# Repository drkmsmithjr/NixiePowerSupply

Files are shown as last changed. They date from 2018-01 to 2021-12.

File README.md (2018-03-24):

# [Nixie Tube Power Supply](https://wp.me/p85ddV-B1 )

See [www.surfncircuits.com](https://wp.me/p85ddV-B1)  for a complete description.  This github repository contains the Kicad Schematic, Spice Simulation, Efficiency Calculations of the 5v to 170v DCM Boost Converter for Powering your Nixie Tubes.   

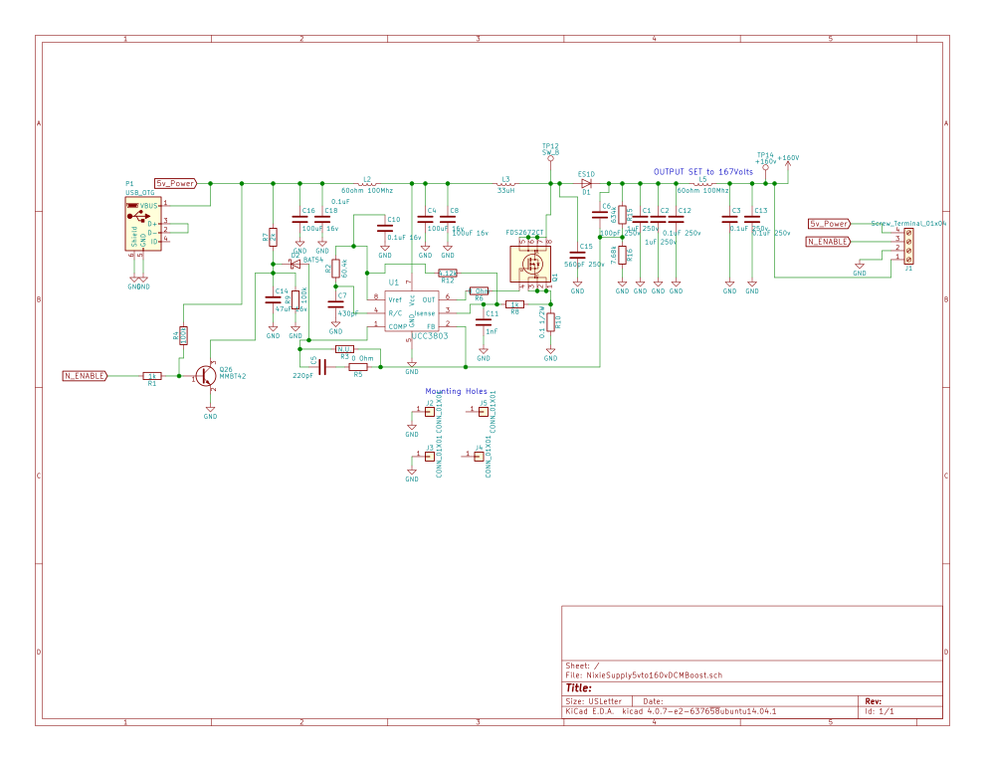
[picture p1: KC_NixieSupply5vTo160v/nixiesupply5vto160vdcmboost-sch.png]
PNG of the Schematic

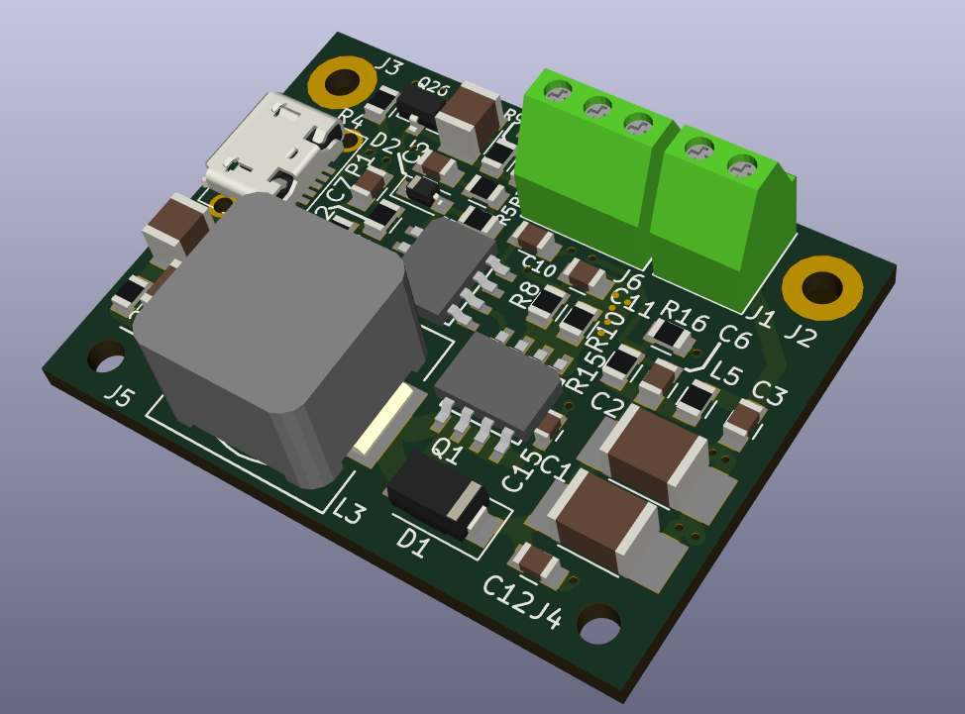
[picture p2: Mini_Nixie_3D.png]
3D image of Rev 3 Mini Board


__KC_NixieSupply5vto160v__:  Kicad schematic, PCB layout, BOM.  The footprint is 1.5" x 1.5" and was described and optimized in Part 2 of the blog.     The Board can be ordered from __oshpark.com__.

__KC_NixieSupply5vto170vMini__:  KiCad schematic, PCB Layout, BOM of the "mini" version of the supply.   This has a footprint of 1.5" x 1" by using smaller output capacitors and using the KiCad power tools to shrink the layout.  This is the system defined by part 3 of the blog.    The layout has all the same constraints as in Part 2.  It still has four mounting holes, a USB input connector and a Terminal output connector.    You can order the board from __oshpark.com__. 

__SimCalcFiles__:  Spice simulation files and DCM Efficiency Calculations.  NOTE: The LTSPICE (TM) simulation has trouble finding an initial operating point.   To get the simulation to start, use the ESC key and press it twice to skip the initial operating point.   This allows the simulation to continue and will provide a good transient response.    

__Datasheeets__: Datasheets for different inductors and the power fet.  In the Kicad Schematic, the part numbers and Digikey (TM) links are listed already.   Also the complete BOM is located in the KICAD Directory.      

See the complete blogs entry at  www.surfncircuits.com
  * [Designing a Small Footprint, Low Profile 5v to 170v Nixie Tube Power Supply (Part 1)](https://wp.me/p85ddV-A8 )
  * [Optimizing the design of the 5v to 170v Nixie Tube Power Supply (Part 2)](https://wp.me/p85ddV-B1 )
  * [KiCad Power Tools Help Shrink The Nixie Tube Power Supply (part 3)](https://wp.me/p85ddV-Ck)

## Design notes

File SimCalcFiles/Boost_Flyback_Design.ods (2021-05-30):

 | Boost Converter Calculator
 |  |  |  |  |  | Estimated: Same Core | NixieTubeMicroSupply | PCA core
 |  |  | DCM Boost Losses | DCM design ETD34 | DCM Boost Same as H | Flyback Calculations | Flyback Calculations | Flyback Calculations
 | Vout | Vout | 167 | 167 | 167 | 167 | 167 | 167
 | Vin | Vin | 5 | 5 | 5 | 5 | 5 | 5
 | Flyback Turns Ratio | Secondary/Primary |  |  |  | 5 | 8 | 10.4
 | Duty for CCM of operation | D_CCM | 0.9700598802395 | 0.9700598802395 | 0.9700598802395 | 0.8697916666667 | 0.8067632850242 | 0.7625570776256
 | Nixie Load (Maximum Current) |  | 3.09E-03 | 3.09E-03 | 3.09E-03 | 3.09E-03 | 3.09E-03 | 3.09E-03
 | Nixie tubes |  | 6 | 6 | 6 | 6 | 10 | 10
 | I out (total | Iout max | 1.85E-02 | 1.85E-02 | 1.85E-02 | 1.85E-02 | 3.09E-02 | 3.09E-02
 | Pout (per tube) |  | 5.16E-01 | 5.16E-01 | 5.16E-01 | 5.16E-01 | 5.16E-01 | 5.16E-01
 | Pout Max total |  | 3.10E+00 | 3.10E+00 | 3.10E+00 | 3.10E+00 | 5.16E+00 | 5.16E+00
 | Efficiency Estimated (see below for actual) |  | 0.73 | 0.73 | 0.73 | 0.73 | 0.86 | 0.86
 | P in (at Pmax estimate) | Pin | 4.241E+00 | 4.241E+00 | 4.241E+00 | 4.24E+00 | 6.00E+00 | 6.00E+00
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

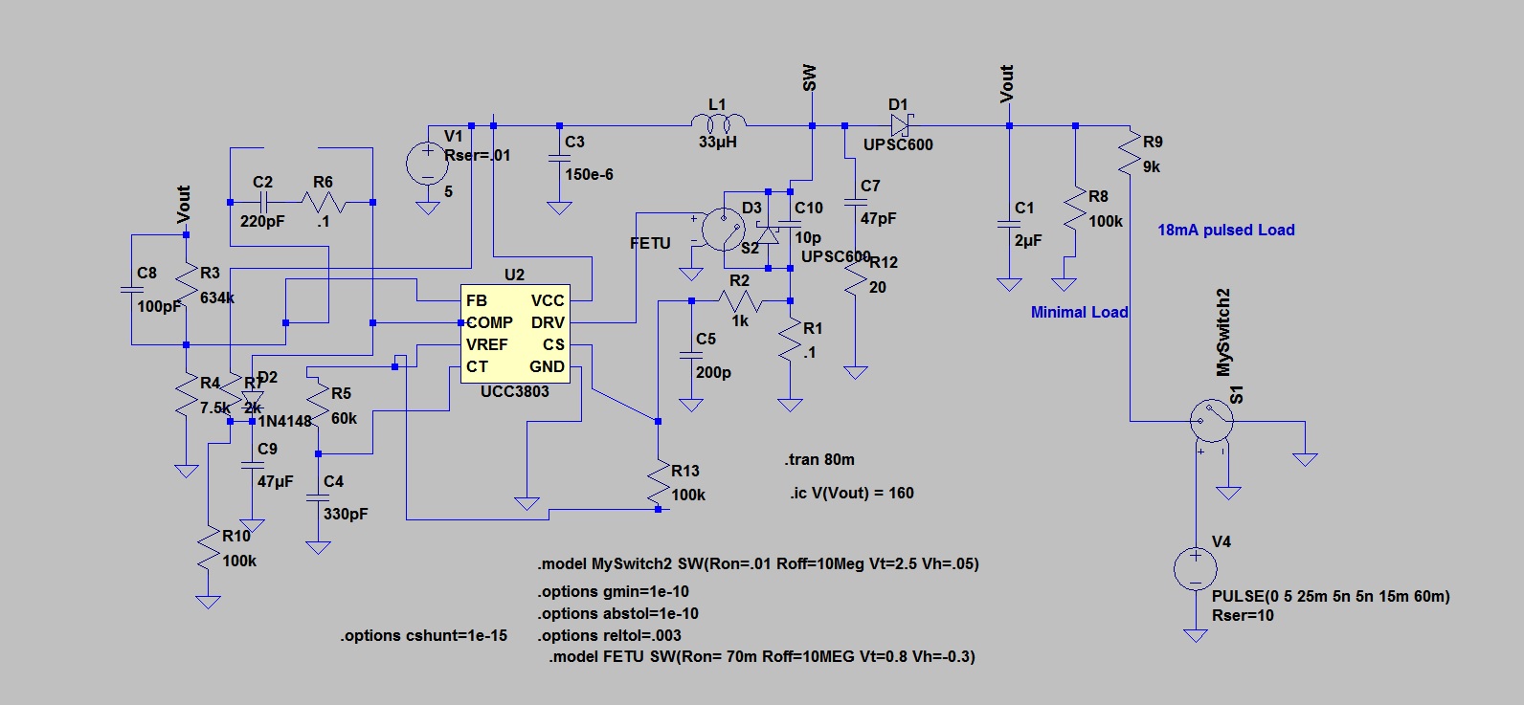
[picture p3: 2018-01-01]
SimCalcFiles/Schematic.jpg

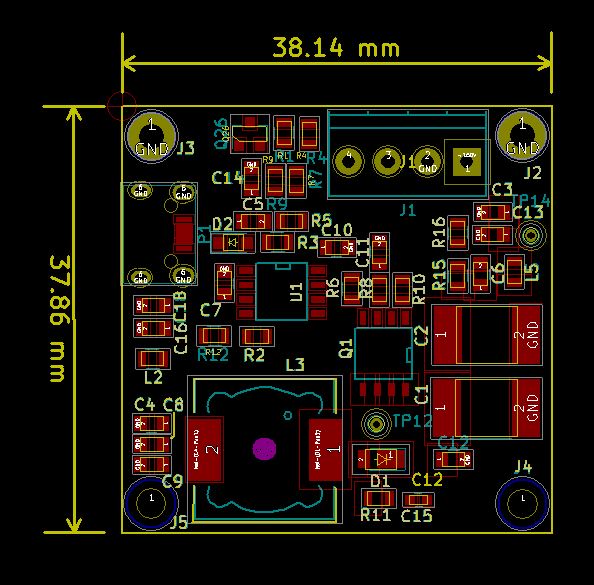
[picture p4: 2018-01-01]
KC_NixieSupply5vTo160v/NixieSupply5vto160vDCMBoost_Picture.JPG

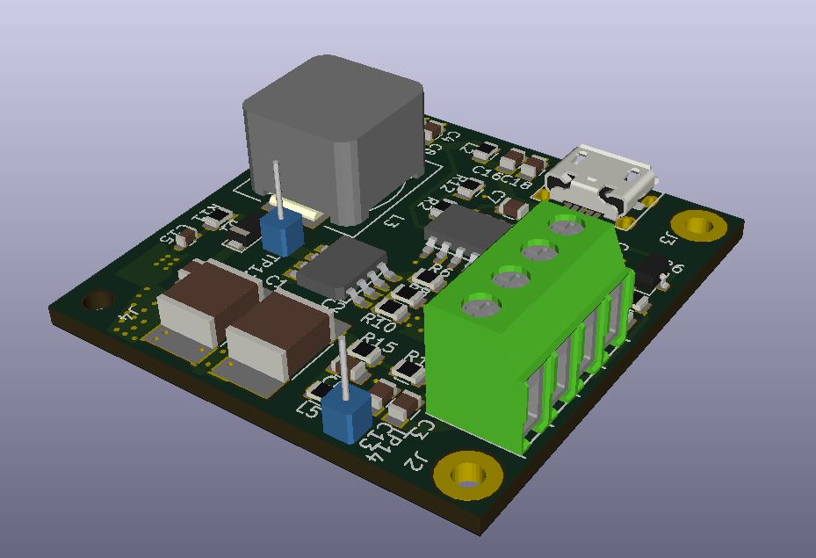
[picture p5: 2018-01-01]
KC_NixieSupply5vTo160v/NixieSupply5vto160vDCMBoost_3dPict.jpg

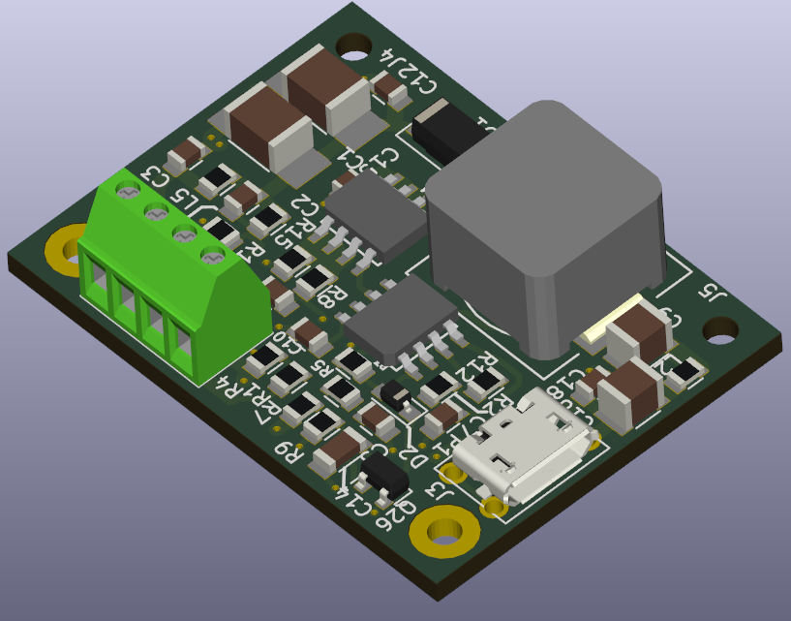
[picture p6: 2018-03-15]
KC_NixieSupply5vTo170vMini/NixieSupply5vto170vDCMBoostMini.png

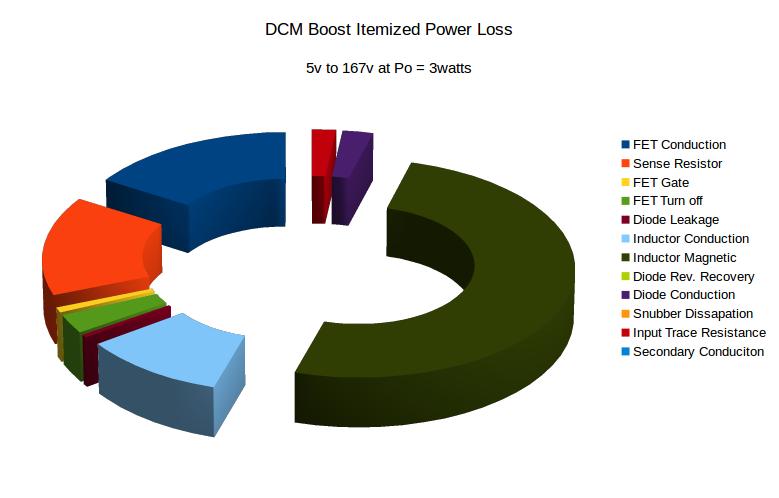
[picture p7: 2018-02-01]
SimCalcFiles/EfficiencyBreakOut.jpg

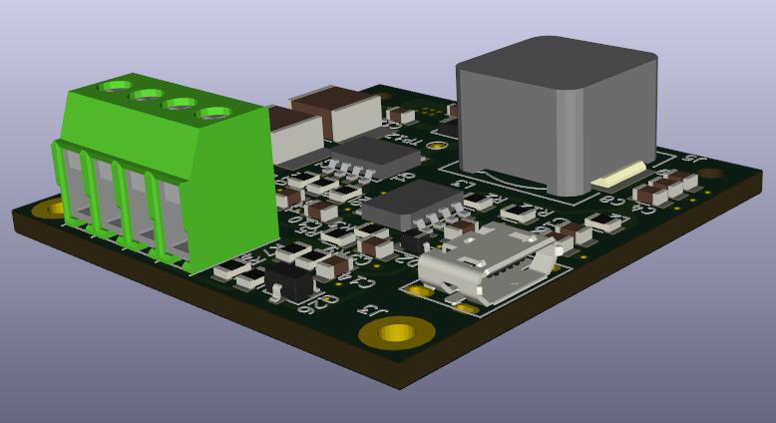
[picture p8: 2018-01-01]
KC_NixieSupply5vTo160v/NixieSupply5vto160vDCMBoost_3DPict2.jpg

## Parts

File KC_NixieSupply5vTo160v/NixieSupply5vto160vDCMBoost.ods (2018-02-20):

Source: | /home/mark/Dropbox/personal/SurfnCircuits/NixiePowerSupply/KC_NixieSupply5vTo160v/NixieSupply5vto160vDCMBoost.sch
Date: | Mon 19 Feb 2018 09:44:40 PM PST
Tool: | Eeschema 4.0.7-e2-6376~60~ubuntu17.10.1
Generator: | /usr/lib/kicad/plugins/bom_csv_grouped_by_value.py
Component Count: | 43
Collated Components:
Item | Qty | Reference(s) | Value | LibPart | Footprint | Datasheet | MPN
1 | 2 | C1, C2 | 1uF 250v | device:C | Capacitors_SMD:C_2220_HandSoldering | https://www.digikey.com/product-detail/en/murata-electronics-north-america/GRM55DR72E105KW01L/490-3550-1-ND/789455 | GRM55DR72E105KW01L
2 | 3 | C3, C12, C13 | 0.1uF 250v | device:C | Capacitors_SMD:C_0805 | https://www.digikey.com/product-detail/en/tdk-corporation/CGA4J3X7T2E104M125AE/445-7965-1-ND/2782533 | CGA4J3X7T2E104M125AE
3 | 3 | C4, C8, C16 | 100uF 16v | device:C | Capacitors_SMD:C_1210 | http://www.digikey.com/product-detail/en/murata-electronics-north-america/GRM21BR61A476ME15L/490-9961-1-ND/5026442 | EMK325ABJ107MM-P
4 | 1 | C5 | 220pF | device:C | Capacitors_SMD:C_0805
5 | 1 | C6 | 100pF 250v | device:C | Capacitors_SMD:C_0805 | https://www.digikey.com/products/en/capacitors/ceramic-capacitors/60?k=C0805C101JAGAC7800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 | CC0805C101JAGAC7800
6 | 1 | C7 | 430pF | device:C | Capacitors_SMD:C_0805 | https://www.digikey.com/product-detail/en/samsung-electro-mechanics/CL21C431JBANNNC/1276-2659-1-ND/3890745 | CL21C431JBANNNC
7 | 1 | C10 | 0.1uF 16v | device:C | Capacitors_SMD:C_0805
8 | 1 | C11 | 1nF | device:C | Capacitors_SMD:C_0805
9 | 1 | C14 | 47uF 16v | device:C | Capacitors_SMD:C_1206 | https://www.digikey.com/product-detail/en/tdk-corporation/C3216JB1C476M160AB/445-11695-1-ND/3953361 | C3216JB1C476M160AB
10 | 1 | C15 | 560pF 250v | device:C | Capacitors_SMD:C_0603 | https://www.digikey.com/product-detail/en/kemet/C0603C561JAGAC7867/399-14990-1-ND/7382539 | C0603C561JAGAC7867
11 | 1 | C18 | 0.1uF | device:C | Capacitors_SMD:C_0805
12 | 1 | D1 | ES1D | device:D | Diodes_SMD:D_SMA_Handsoldering | https://www.digikey.com/product-detail/en/on-semiconductor/ES1D/ES1DFSCT-ND/458940 | ES1D
13 | 1 | D2 | BAT54 | device:D_Schottky | Diodes_SMD:D_SOD-323_HandSoldering | https://www.digikey.com/product-detail/en/diodes-incorporated/BAT54WS-7-F/BAT54WS-FDICT-ND/804892 | BAT54WS-7-F
14 | 1 | J1 | Screw_Terminal_01x04 | conn:Screw_Terminal_01x04 | TerminalBlock_Phoenix:TerminalBlock_Phoenix_PT-3.5mm_4pol | https://www.digikey.com/scripts/DkSearch/dksus.dll?Detail&itemSeq=248943251&uq=636514658010412978 | 1984633
15 | 2 | J2, J3 | CONN_01X01 | conn:Conn_01x01 | Mounting_Holes:MountingHole_2.2mm_M2_Pad
16 | 2 | J4, J5 | CONN_01X01 | conn:Conn_01x01 | Mounting_Holes:MountingHole_2.2mm_M2
17 | 2 | L2, L5 | 60ohm 100Mhz | device:L | Resistors_SMD:R_0805 | https://www.digikey.com/product-detail/en/taiyo-yuden/BKP2125HS600-T/587-1932-1-ND/1465402 | BKP2125HS600-T
18 | 1 | L3 | 33uH | device:L | NixieSupply5vto160vDCMBoost_socket:Choke_SMD_12x12mm_Wurth_WE-PD | https://www.digikey.com/products/en/inductors-coils-chokes/fixed-inductors/71?k=7447709330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 | 7447709330
19 | 1 | P1 | USB_OTG | conn:USB_OTG | NixieSupply5vto160vDCMBoost_socket:USB_Micro-B_Wurth_3A_Non-OVAL-Drill | https://www.digikey.com/product-detail/en/wurth-electronics-inc/629105150521/732-5960-1-ND/5047555 | 629105150521
20 | 1 | Q1 | FDS2672CT | transistors:FDMS86255ET150 | etaclock:SOIC-8-N | https://www.digikey.com/product-detail/en/on-semiconductor/FDS2672/FDS2672CT-ND/1217902 | FDS2672CT-ND
21 | 1 | Q26 | MMBT42 | transistors:MMBT3904 | TO_SOT_Packages_SMD:SOT-23 | http://www.digikey.com/product-detail/en/micro-commercial-co/MMBTA42-TP/MMBTA42TPMSCT-ND/717401
22 | 2 | R1, R8 | 1k | device:R | Resistors_SMD:R_0805
23 | 1 | R2 | 60.4k | device:R | Resistors_SMD:R_0805
24 | 1 | R3 | N.U. | device:R | Resistors_SMD:R_0805
25 | 2 | R4, R9 | 100k | device:R | Resistors_SMD:R_0805
26 | 2 | R5, R6 | 0 Ohm | device:R | Resistors_SMD:R_0805
27 | 1 | R7 | 2k | device:R | Resistors_SMD:R_0805
28 | 1 | R10 | 0.1 1/2W | device:R | Resistors_SMD:R_0805 | https://www.digikey.com/product-detail/en/panasonic-electronic-components/ERJ-6DSFR10V/P19308CT-ND/6004663 | ERJ-6DSFR10V
29 | 1 | R12 | 4.12k | device:R | Resistors_SMD:R_0805
30 | 1 | R15 | 634k | device:R | Resistors_SMD:R_0805
31 | 1 | R16 | 7.68k | device:R | Resistors_SMD:R_0805
32 | 1 | U1 | UCC3803 | NixieSupply5vto160vDCMBoost-cache:AAC243 | NixieSupply5vto160vDCMBoost_socket:SOIC-8-N | https://www.digikey.com/products/en/integrated-circuits-ics/pmic-voltage-regulators-dc-dc-switching-controllers/715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 | UCC3803DTR

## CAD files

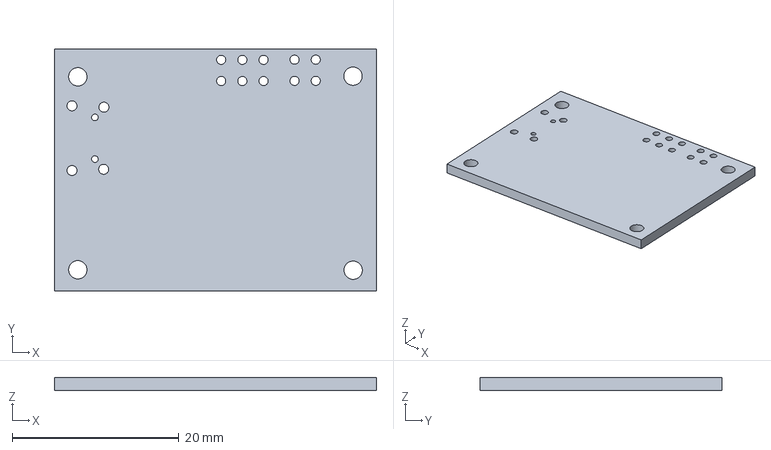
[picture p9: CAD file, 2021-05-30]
KC_NixieSupply5vTo170vMini/NixieSupply5vto170vDCMBoostMini.step
38.6 x 29.0 x 1.60 mm

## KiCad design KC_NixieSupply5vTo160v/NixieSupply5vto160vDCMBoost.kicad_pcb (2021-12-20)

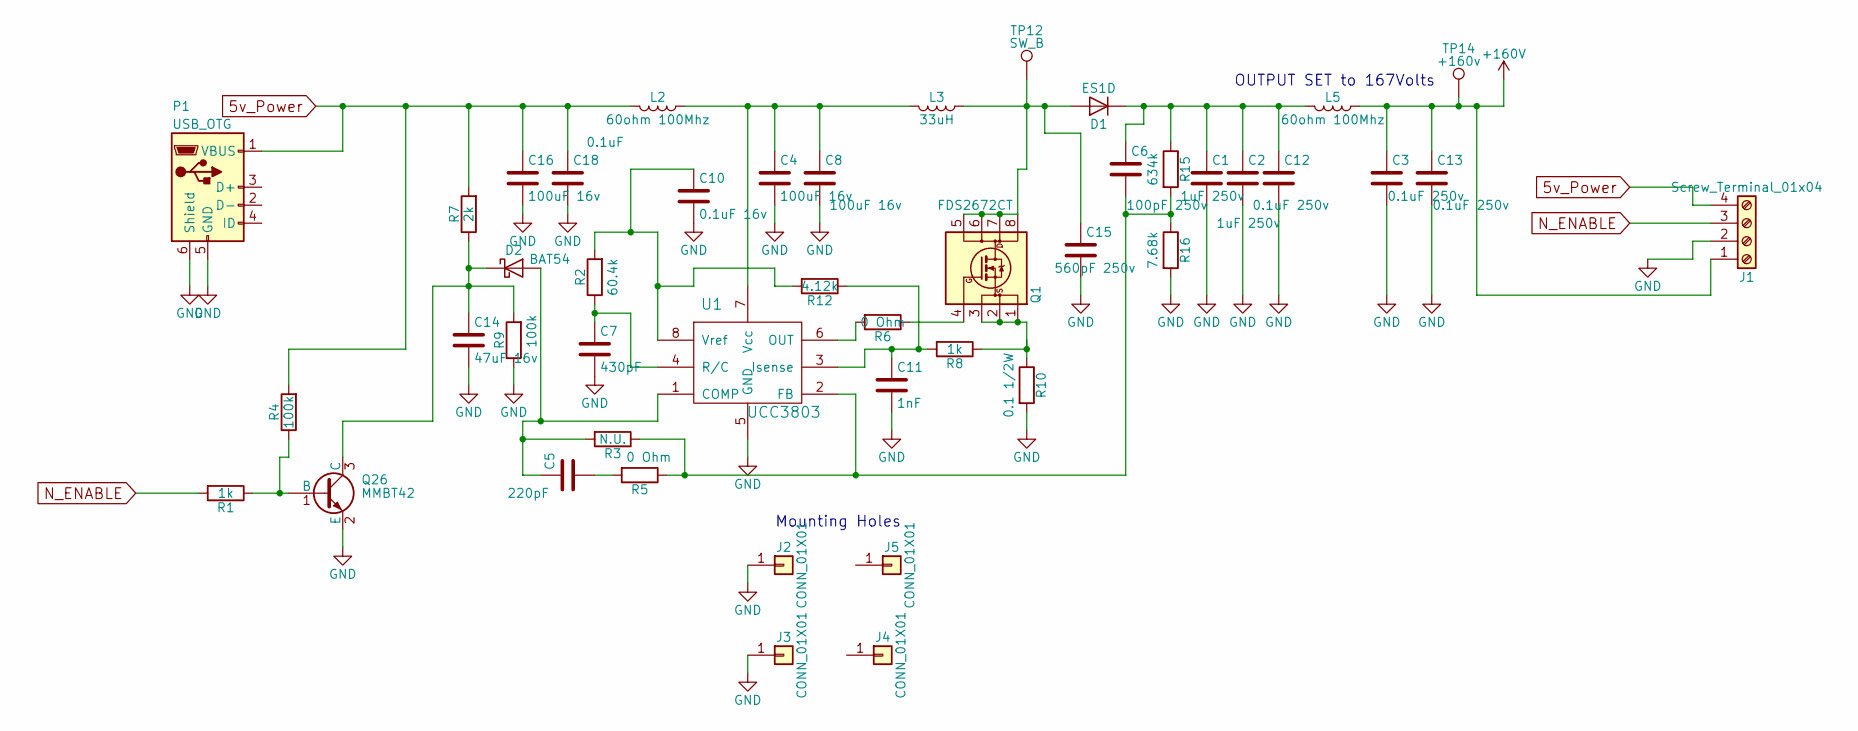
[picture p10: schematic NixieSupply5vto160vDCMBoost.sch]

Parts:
C1, C2: 1uF 250v; C_2220_HandSoldering; MPN GRM55DR72E105KW01L
C3, C12, C13: 0.1uF 250v; C_0805; MPN CGA4J3X7T2E104M125AE
C4, C8, C16: 100uF 16v; C_1210; MPN EMK325ABJ107MM-P
C5: 220pF; C_0805
C6: 100pF 250v; C_0805; MPN CC0805C101JAGAC7800
C7: 430pF; C_0805; MPN CL21C431JBANNNC
C10: 0.1uF 16v; C_0805
C11: 1nF; C_0805
C14: 47uF 16v; C_1206; MPN C3216JB1C476M160AB
C15: 560pF 250v; C_0603; MPN C0603C561JAGAC7867
C18: 0.1uF; C_0805
D1: ES1D; D_SMA_Handsoldering; MPN ES1D
D2: BAT54; D_SOD-323_HandSoldering; MPN BAT54WS-7-F
J1: Screw_Terminal_01x04; TerminalBlock_Phoenix_PT-3.5mm_4pol; MPN 1984633
J2, J3: CONN_01X01; MountingHole_2.2mm_M2_Pad
J4, J5: CONN_01X01; MountingHole_2.2mm_M2
L2: 60ohm 100Mhz; R_0805; MPN BKP2125HS600-T
L3: 33uH; Choke_SMD_12x12mm_Wurth_WE-PD; MPN 7447709330
L5: 60ohm 100Mhz; R_0805
P1: USB_OTG; USB_Micro-B_Wurth_3A_Non-OVAL-Drill; MPN 629105150521
Q1: FDS2672CT; SOIC-8-N; MPN FDS2672CT-ND
Q26: MMBT42; SOT-23
R1, R8: 1k; R_0805
R2: 60.4k; R_0805
R3: N.U.; R_0805
R4, R9: 100k; R_0805
R5, R6: 0 Ohm; R_0805
R7: 2k; R_0805
R10: 0.1 1/2W; R_0805; MPN ERJ-6DSFR10V
R12: 4.12k; R_0805
R15: 634k; R_0805
R16: 7.68k; R_0805
TP12: SW_B; PINTST
TP14: +160v; PINTST
U1: UCC3803; SOIC-8-N; MPN UCC3803DTR

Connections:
5v_Power: C16.1, C18.1, J1.4, L2.2, P1.1 (VBUS), R4.2, R7.2
+160V: C3.1, C13.1, J1.1, L5.1, TP14.1
GND: C1.2, C2.2, C3.2, C4.2, C7.2, C8.2, C10.2, C11.2, C12.2, C13.2, C14.2, C15.2, C16.2, C18.2, J1.2, J2.1, J3.1, P1.5 (GND), P1.6 (Shield), Q26.2 (E), R9.1, R10.2, R16.2, U1.5 (GND)
N_ENABLE: J1.3, R1.2
unnamed: C1.1, C2.1, C6.1, C12.1, D1.1 (K), L5.2, R15.1
unnamed: C4.1, C8.1, L2.1, L3.2, U1.7 (Vcc)
unnamed: C5.1, D2.2 (A), R3.2, U1.1 (COMP)
unnamed: C5.2, R5.2
unnamed: C6.2, R3.1, R5.1, R15.2, R16.1, U1.2 (FB)
unnamed: C7.1, R2.1, U1.4 (R/C)
unnamed: C10.1, R2.2, R12.2, U1.8 (Vref)
unnamed: C11.1, R8.2, R12.1, U1.3 (Isense)
unnamed: C14.1, D2.1 (K), Q26.3 (C), R7.1, R9.2
unnamed: C15.1, D1.2 (A), L3.1, Q1.5 (D), Q1.6 (D), Q1.7 (D), Q1.8 (D), TP12.1
unnamed: P1.2 (D-), P1.3 (D+)
unnamed: Q1.1 (S), Q1.2 (S), Q1.3 (S), R8.1, R10.1
unnamed: Q1.4 (G), R6.1
unnamed: Q26.1 (B), R1.1, R4.1
unnamed: R6.2, U1.6 (OUT)

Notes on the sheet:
Mounting Holes
OUTPUT SET to 167Volts

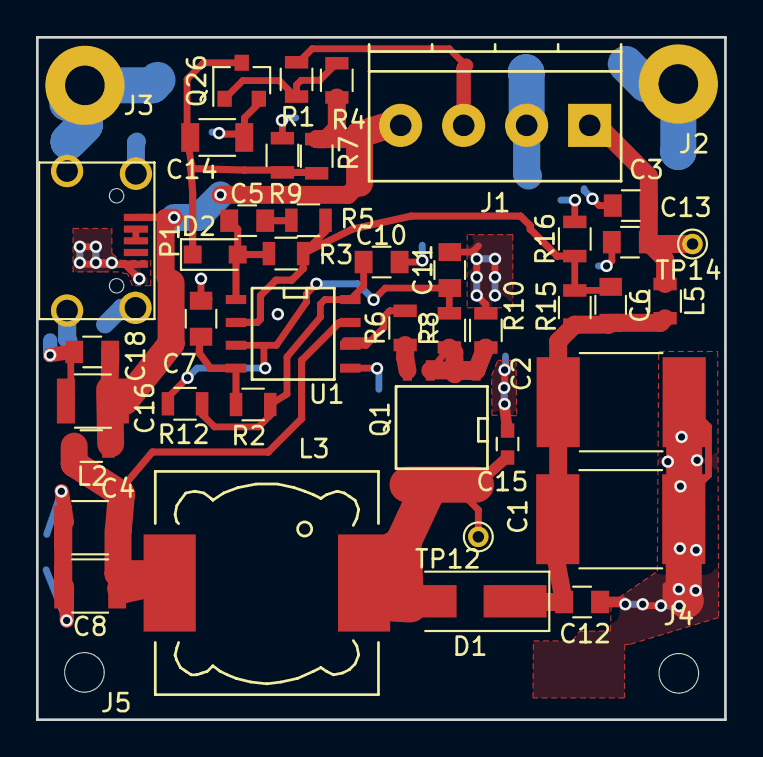
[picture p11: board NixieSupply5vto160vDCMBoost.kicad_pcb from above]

Board: 2 copper layers, 38.2 x 37.9 mm, 45 parts (0 on the bottom side), 19 nets.

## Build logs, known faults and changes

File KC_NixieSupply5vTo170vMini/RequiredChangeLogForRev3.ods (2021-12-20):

 | Changes Needed since Rev3 was produced on Jul 2021
Rev 3 Change List
1 | Update the C1812 output capacitor pads to be NON-Handsoldered in order for PCBWAY to produce then with a machine.

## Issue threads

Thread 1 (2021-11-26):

Files seem to be corrupt

BlackStar-EoP, 2021-11-26:
Zip files with Gerber files cannot be opened, with KiCad, all files give error messages.

drkmsmithjr, 2021-12-19:
Hi BlackStar-EoP.  I downloaded your fork and was not able to reproduce your error.  Both of power power supply gerber files we able to be read by the Kicad GerbView.   For example, for this file.  Please unzip all the files,  then start up GerbView from within the Kicad Tools area (CNTL-G).   Go to open the files and select all the files together.  They should load.    As you may know, the Gerber Files are what are needed for manufacturing.

The PCB and Schematic files were written in Kicad 4.0 and some conversion may be required to run with the latest version of Kicad (5.0).  If you are having issues with this I can work to load a version 5.0.  Let me know.

thanks.

[NixieSupply5vto160vDCMBoost_Rev3.zip](https://github.com/drkmsmithjr/NixiePowerSupply/files/7740323/NixieSupply5vto160vDCMBoost_Rev3.zip)

drkmsmithjr, 2021-12-20:
Kicad version 5.0 have been updated to Git.

BlackStar-EoP, 2021-12-20:
Hey drkmsmithjr, I have now tried ZIP files from both my fork and your original ones. They seem to be working now. I am unsure what has happened here to be honest. Basically, every file I downloaded was corrupt (diptrace couldn't even open the loose gerber files), the zip files couldn't be opened, but I can't reproduce that right now.

I do have the corrupt files though, NixieSupply5vto160vDCMBoost_Rev3.zip is 160kB while the real version is 41kB. Clearly something went wrong here. Was downloaded via browser, not via git clone.

I'd say this issue can be closed :)

drkmsmithjr, 2021-12-24:
Thanks for the confirmation.    I'll close the issue.

Closed 2021-12-24.

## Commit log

2018-01-01 Initial Upload
    Draft of the blog data files, simulation files. Licence, README
    started but needs to be completed
    [Boost_Flyback_Design.xlsx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]
2018-01-01 change the bom file
    [NixieSupplyBOM.csv, _saved_NixieSupply5vto160vDCMBoost.sch]
2018-01-01 Update .gitignore
    Added Kicad backup files. Don't need these.
2018-01-01 New Gerber Files
    Updated the layout of the USB connector to remove the Slots and replace
    with holes.
    [NixieSupply5vto160vDCMBoost-B.Cu.gbl, NixieSupply5vto160vDCMBoost-B.Mask.gbs, NixieSupply5vto160vDCMBoost-B.SilkS.gbo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]
2018-01-01 updated layout
    latest. misc
    [NixieSupply5vto160vDCMBoost.kicad_pcb]
2018-01-01 removed the backup files
    from Kicad
2018-01-06 Update .gitattributes
    changed content to Kicad Layou
2018-01-07 Flyback Efficiency Calculations
    Added a Efficiency calculations for a flyback converter using similar
    parts, but with an off the self 8.5uH 1:5 turns ration flyback
    transformer. the DCM boost still looks like the highest efficiency.
    [Boost_Flyback_Design.ods, Boost_Flyback_Design.xlsx, NixieSupply5vto160vDCMBoost.sch]
2018-02-01 Latest updates for the verification Blog
    [Boost_Flyback_Design.ods, NixieSupply5vto160vDCMBoost.kicad_pcb, NixieSupply5vto160vDCMBoost.sch]
2018-02-01 new verification files added during experimental state
    [NixieSupplyBOM.ods, powernotes2.ods]
2018-02-01 New Gerber's for the final design
    [NixieSupply5vto160vDCMBoost-B.Cu.gbl, NixieSupply5vto160vDCMBoost-B.Mask.gbs, NixieSupply5vto160vDCMBoost-B.SilkS.gbo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]
2018-02-03 NEw BOM with Part 2 of Blog
    [Boost_Flyback_Design.ods, NixieSupply5vto160vDCMBoost.ods, NixieSupplyBOM.csv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]
2018-02-03 Updated gerber file generation for part 2 of blog
    [NixieSupply5vto160vDCMBoost-B.Cu.gbl, NixieSupply5vto160vDCMBoost-B.Mask.gbs, NixieSupply5vto160vDCMBoost-B.SilkS.gbo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]
2018-02-04 Added the new Mini Layout file to the repository. This is currently a work in progress
    [NixieSupply5vto170vDCMBoostMini.kicad_pcb, NixieSupply5vto170vDCMBoostMini.sch]
2018-02-04 started layout and fixed netclass for the high current 5v input
    [NixieSupply5vto170vDCMBoostMini.kicad_pcb]
2018-02-05 Finished the Gerber file for Mini Layout. Need to add OSHW logo to bottom.
    [NixieSupply5vto170vDCMBoostMini-B.Cu.gbl, NixieSupply5vto170vDCMBoostMini-B.Mask.gbs, NixieSupply5vto170vDCMBoostMini-B.SilkS.gbo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]
2018-02-05 Update README.md
    Added copyright to the PCB board
2018-02-05 Updated the copyright information to Mark Smith and added www.surfncircuits.com to Boards Also added a part number and date code. yyww (last two digits of year and ww is the work week) NixieSupply Re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
    [NixieSupply5vto160vDCMBoost-B.Cu.gbl, NixieSupply5vto160vDCMBoost-B.Mask.gbs, NixieSupply5vto160vDCMBoost-B.SilkS.gbo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]
2018-02-07 Schematic of the 5v to 170v DCM boost converter
2018-02-07 PNG of the schematic
2018-02-14 Added OSHW_LOGO and the copyright symbol to both Files. Also updated the gerber files and finished the Mini layout solution.
    [NixieSupply5vto160vDCMBoost-B.Cu.gbl, NixieSupply5vto160vDCMBoost-B.Mask.gbs, NixieSupply5vto160vDCMBoost-B.SilkS.gbo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]
2018-02-20 Corrected the C6 BOM entry. Also created a BOM for the MINI version of the layout.
    [Boost_Flyback_Design.ods, NixieSupply5vto160vDCMBoost.ods, NixieSupply5vto170vDCMBoostMini.ods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]
2018-02-20 removed backup files
    [NixieSupply5vto160vDCMBoost.kicad_pcb]
2018-02-20 test update
    [NixieSupply5vto170vDCMBoostMini.sch]
2018-02-24 restored PCB file I accidentally deleted before.
    [NixieSupply5vto160vDCMBoost.kicad_pcb]
2018-03-04 Updated the gerber files to include a ground pad for R10 to reduce resistance. Also updated the net classes for the blog entry.
    [NixieSupply5vto160vDCMBoost.kicad_pcb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]
2018-03-15 New Rev 3 for the Original Nixie Power Supply 1. Corner Mounting Holes are now Solid. Per the tip by comment reader 2. The original supply has a better ground connection for the USB input, But the US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
    [NixieSupply5vto160vDCMBoost-B.Cu.gbl, NixieSupply5vto160vDCMBoost-B.Mask.gbs, NixieSupply5vto160vDCMBoost-B.SilkS.gbo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]
2018-03-23 Rev 3 of the Mini Nixie Tube Power supply schematic and layout. Changed the output connector to have 1.25mm spacing with nearest conductor
    Moved traces around to allow forn two output connectors. Changed
    the size of the 47uF 16v capacitor to a 1210 package.
    [NixieSupply5vto170vDCMBoostMini.kicad_pcb, NixieSupply5vto170vDCMBoostMini.ods, NixieSupply5vto170vDCMBoostMini.sch]
2018-03-24 New Gerbers for Rev 3 of the supply. Improved spacing for the 170v output connector. Two output connectors to the correct spacing
    [NixieSupply5vto170vDCMBoostMini-B.Cu.gbl, NixieSupply5vto170vDCMBoostMini-B.Mask.gbs, NixieSupply5vto170vDCMBoostMini-B.SilkS.gbo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]
2021-05-30 This saves Kicad version 4.0 o of the nixie power supplies.
    [Boost_Flyback_Design.ods, NixieSupply5vto160vDCMBoost-2021-01-05-17-11-23.sch, NixieSupply5vto160vDCMBoost-2021-02-09-22-13-55.sch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]
2021-07-16 The NewOrigin Zip file was used for the PCBWAY order This BOM was used for the PCBway order Updated the files to Rev 5 of Kicad
    [NixieSupply5vto160vDCMBoost.sch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]
2021-07-16 Files for the pcbway order
    [NixieSupply5vto170vDCMBoostMini-2021-05-30-13-46-07.sch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]
2021-07-16 added all files
    [NixieSupply5vto160vDCMBoost-2021-06-01-09-09-31.sch]
2021-12-20 version Kicad version 5. 170vmini supply is up to date with 3D images.
    [NixieSupply5vto160vDCMBoost.kicad_pcb, RequiredChangeLogForRev3.ods]
